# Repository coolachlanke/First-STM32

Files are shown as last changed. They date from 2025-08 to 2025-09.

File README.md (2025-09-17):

# My First STM32 Project

Simple PCB with minimum circuit plus SWD, USART, I2C and USB. Designed wholly in KiCAD 9.

---
Take a look a the fully sick 3D render:

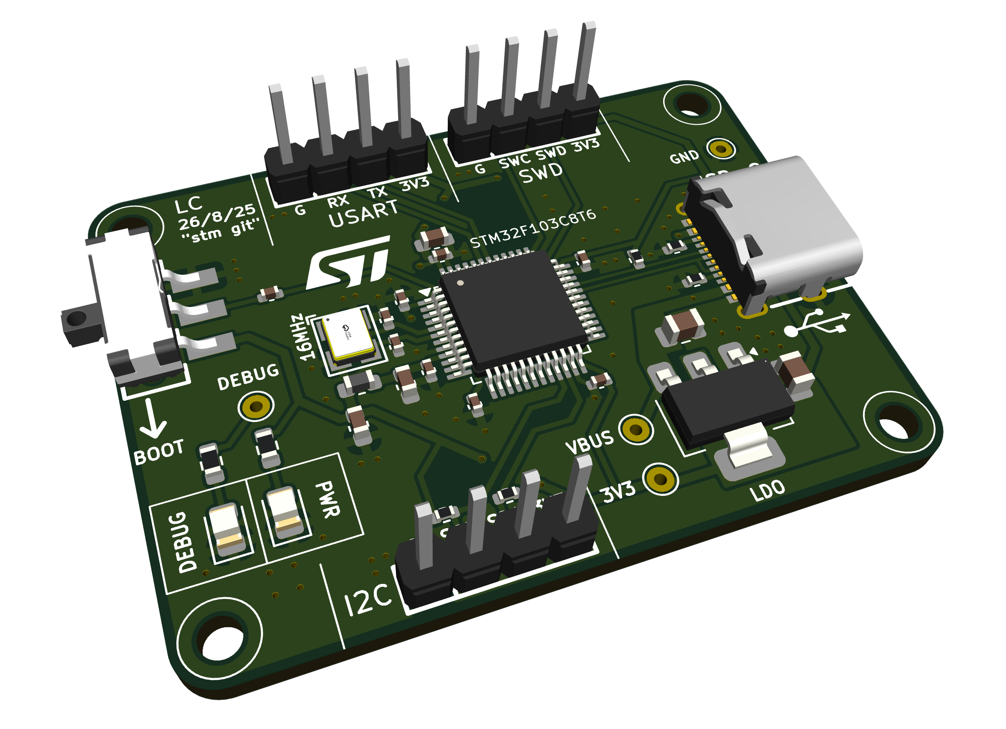
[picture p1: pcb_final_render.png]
pcb_render

---
..and now take a look at the fully sick assembled board:

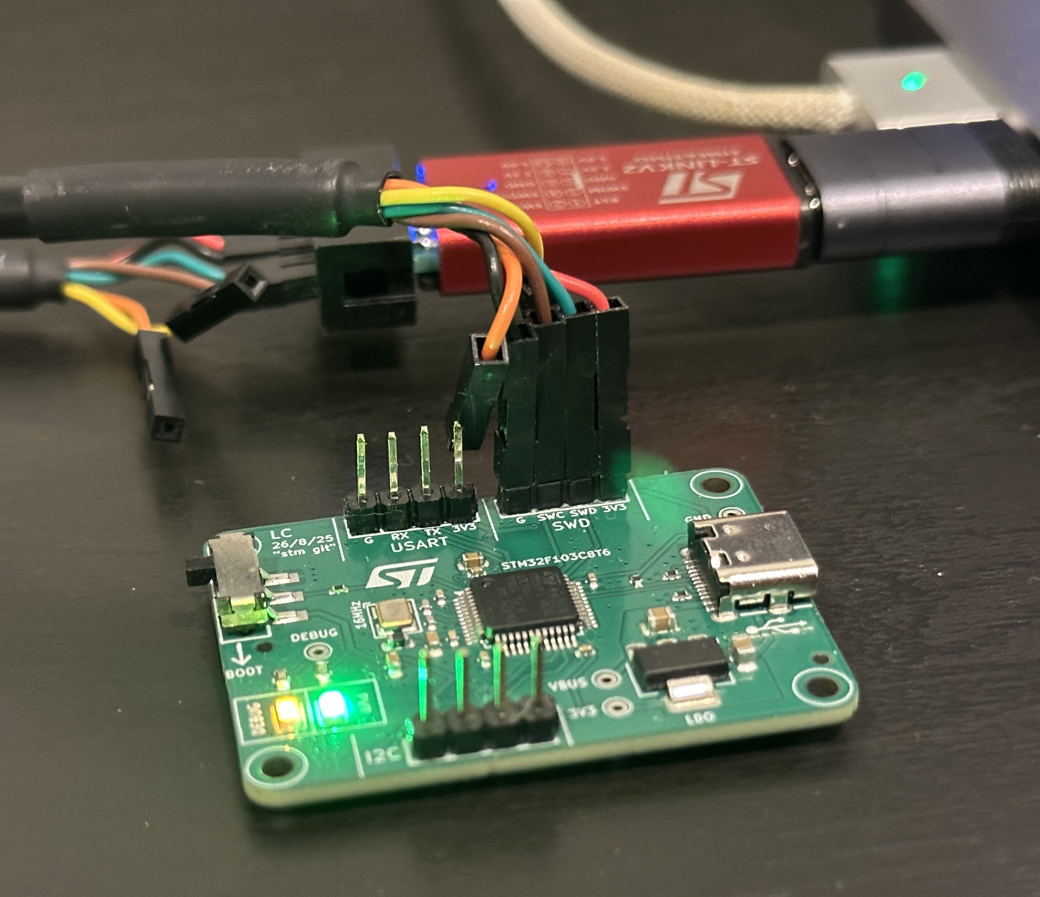
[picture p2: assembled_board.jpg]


The board's indicator LEDs are both on. The green 'PWR' LED indicates the 3V3 bus is live. The orange 'DEBUG' LED is a result of the 'blinky' routine being in the HIGH state.

---
The following HAL-free c script is used to blink the DEBUG LED by writing directly to memory-mapped peripheral registers.

```#include <stdint.h>

int main(void) {
    // Enable GPIOC clock
    volatile uint32_t *rcc_apb2enr = (volatile uint32_t *)0x40021018;
    *rcc_apb2enr |= (1 << 4); // Set IOPCEN (bit 4)

    // Configure PC13 as output push-pull, 10 MHz
    volatile uint32_t *gpioc_crh = (volatile uint32_t *)0x40011004;
    *gpioc_crh &= ~(0xF << 20); // Clear MODE13 and CNF13
    *gpioc_crh |= (0x1 << 20); // MODE13 = 01 (output 10 MHz), CNF13 = 00 (push-pull)

    // DR Register
    volatile uint32_t *gpioc_odr = (volatile uint32_t *)0x4001100C;

    // SysTick Registers
    volatile uint32_t *systick_ctrl = (volatile uint32_t *)0xE000E010;
    volatile uint32_t *systick_load = (volatile uint32_t *)0xE000E014;
    volatile uint32_t *systick_val  = (volatile uint32_t *)0xE000E018;

    // SysTick Init
    *systick_load = (8000000 / 1000) - 1;  // Reload for 1ms tick
    *systick_val  = 0;                     // Clear current value
    *systick_ctrl = (1 << 2) | (1 << 0);   // CLKSOURCE=CPU, ENABLE=1

    // Delay Function
    void delay_ms(uint32_t ms) {
        for (uint32_t i = 0; i < ms; ++i) {
            while (((*systick_ctrl) & (1 << 16)) == 0);
        }
    }

    // Main Blink Loop
    while (1) {
        *gpioc_odr &= ~(1 << 13);  // Set PC13 LOW
        delay_ms(250);

        *gpioc_odr |= (1 << 13);   // Set PC13 HIGH
        delay_ms(250);
    }
}

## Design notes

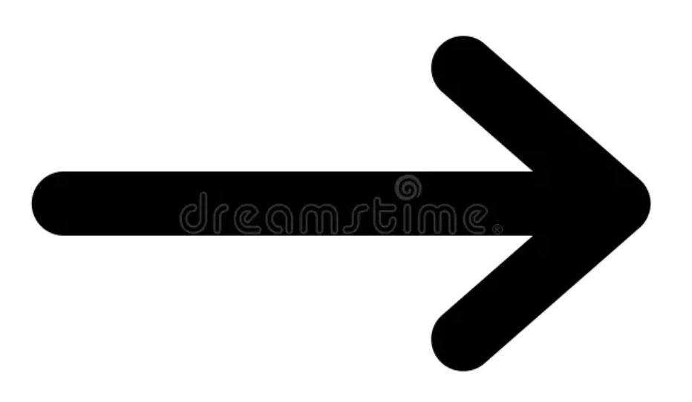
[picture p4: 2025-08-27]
arron.png

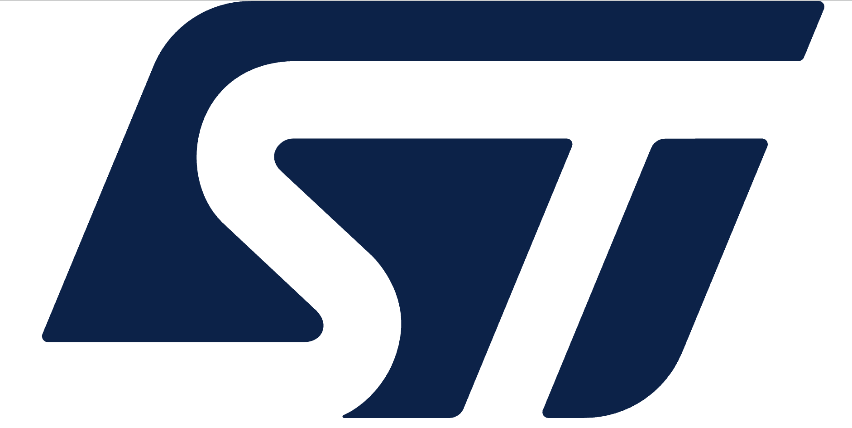
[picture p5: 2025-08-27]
st.png

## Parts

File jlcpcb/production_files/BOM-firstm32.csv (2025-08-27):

Comment | Designator | Footprint | LCSC | Quantity
16MHz | Y1 | OSC-SMD_4P-L3.2-W2.5-BL | C13738 | 1
120R @ 100MHz | FB1 | L_0603_1608Metric | C14709 | 1
10n | C6 | C_0402_1005Metric | C15195 | 1
100n | C1,C2,C3,C4,C9 | C_0402_1005Metric | C1525 | 5
1u | C7,C8 | C_0603_1608Metric | C15849 | 2
10u | C5 | C_0603_1608Metric | C19702 | 1
1k | R6 | R_0603_1608Metric | C21190 | 1
YELLOW | D2 | LED_0805_2012Metric | C2296 | 1
GREEN | D1 | LED_0805_2012Metric | C2297 | 1
470R | R5 | R_0603_1608Metric | C23179 | 1
10k | R1 | C_0402_1005Metric | C25744 | 1
1k5 | R4,R7,R8 | R_0402_1005Metric | C25867 | 3
5k1 | R2,R3 | R_0402_1005Metric | C25905 | 2
Conn_01x04_Pin | J2,J3,J4 | HDR-TH_4P-P2.54-V-M | C2691448 | 3
USB_C_Receptacle_USB2.0_16P | J1 | USB-C-SMD_TYPE-C-6PIN-2MD-073 | C2765186 | 1
10p | C10,C11 | C_0402_1005Metric | C32949 | 2
22u | C12,C13 | C_0805_2012Metric | C45783 | 2
AMS1117-3.3 | U1 | SOT-223-3_TabPin2 | C6186 | 1
STM32F103C8T6 | U2 | LQFP-48_7x7mm_P0.5mm | C8734 | 1
SW_SPDT | SW1 | SW-SMD_K3-1280S-K1 | C92658 | 1
TestPoint | TP4 | TestPoint_THTPad_D1.5mm_Drill0.7mm |  | 1
TestPoint | TP2 | TestPoint_THTPad_D1.5mm_Drill0.7mm |  | 1
TestPoint | TP1 | TestPoint_THTPad_D1.5mm_Drill0.7mm |  | 1
TestPoint | TP3 | TestPoint_THTPad_D1.5mm_Drill0.7mm |  | 1

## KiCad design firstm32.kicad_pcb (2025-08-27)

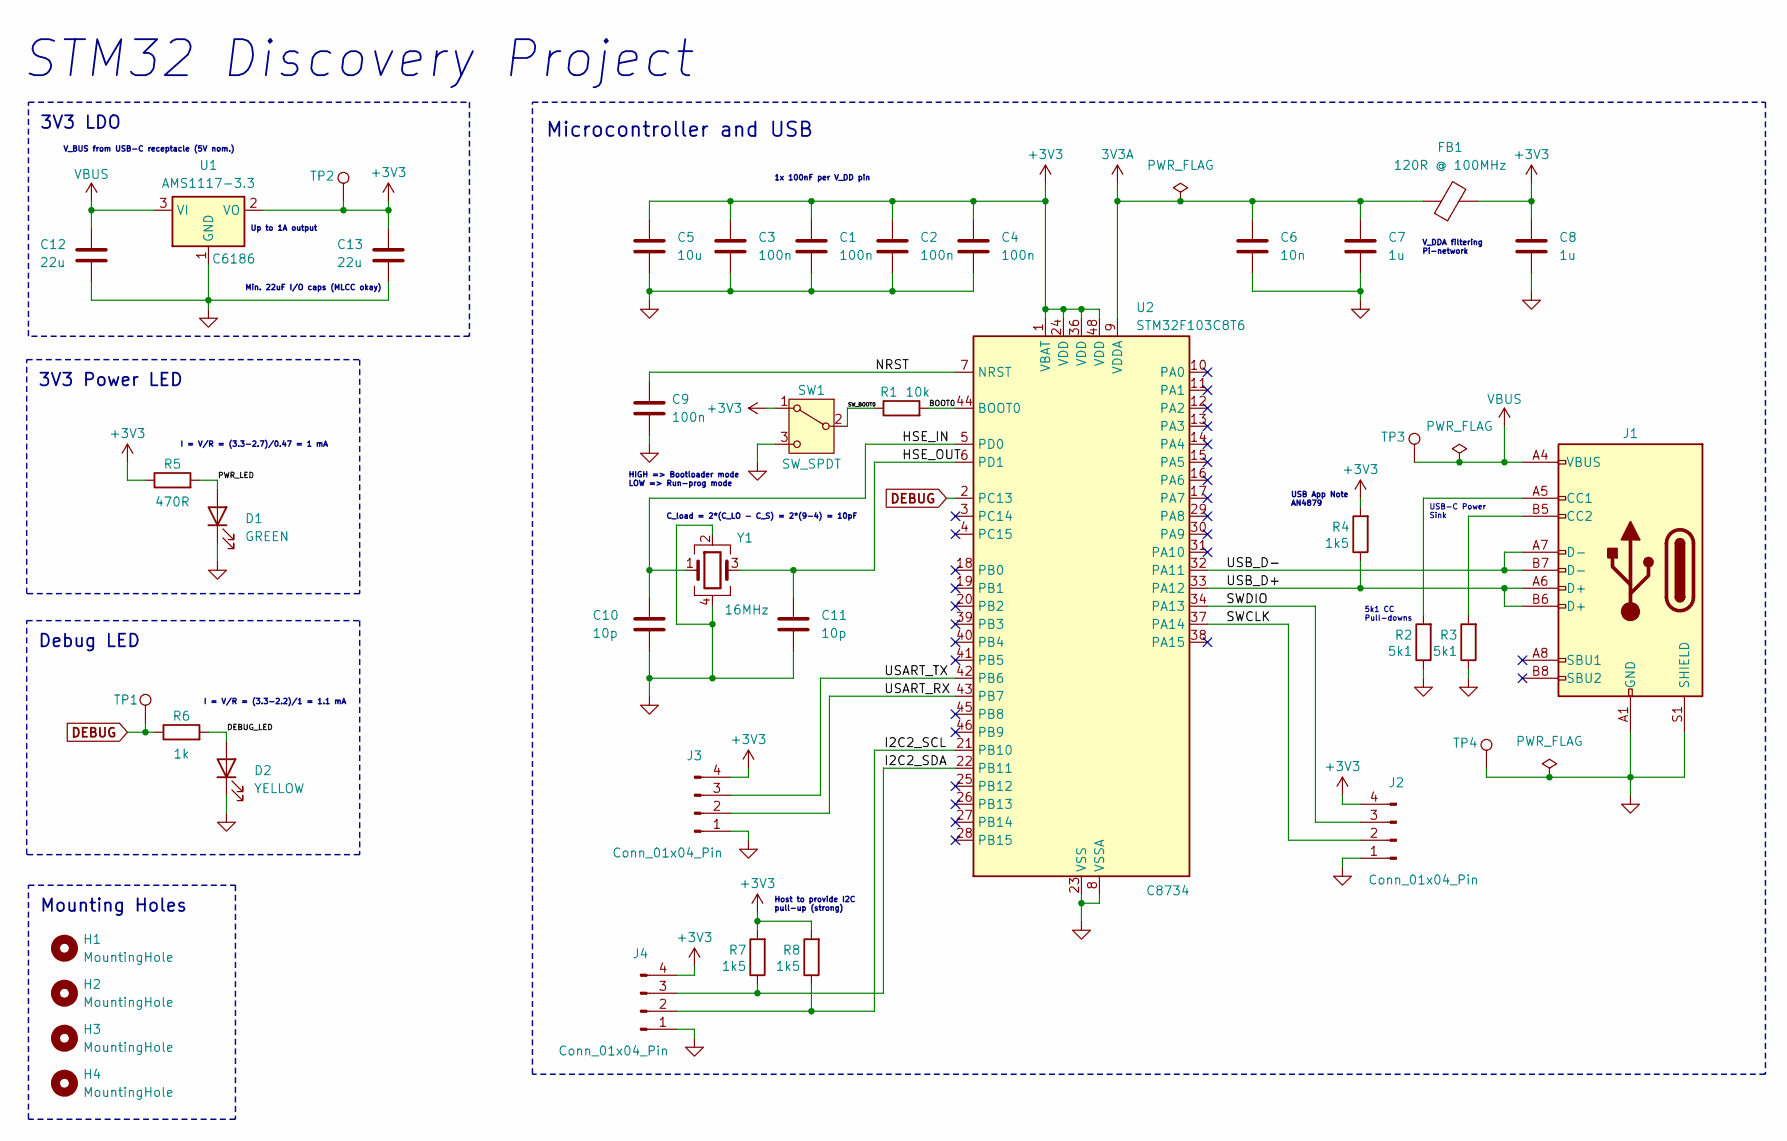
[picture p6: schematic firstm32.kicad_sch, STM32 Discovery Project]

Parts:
C1, C2, C3, C4, C9: 100n; C_0402_1005Metric; LCSC C1525
C5: 10u; C_0603_1608Metric; LCSC C19702
C6: 10n; C_0402_1005Metric; LCSC C15195
C7, C8: 1u; C_0603_1608Metric; LCSC C15849
C10, C11: 10p; C_0402_1005Metric; LCSC C32949
C12, C13: 22u; C_0805_2012Metric; LCSC C45783
D1: GREEN; LED_0805_2012Metric; LCSC C2297
D2: YELLOW; LED_0805_2012Metric; LCSC C2296
FB1: 120R @ 100MHz; L_0603_1608Metric; LCSC C14709
H1, H2, H3, H4: MountingHole; MountingHole_2.2mm_M2
J1: USB_C_Receptacle_USB2.0_16P; USB-C-SMD_TYPE-C-6PIN-2MD-073; LCSC C2765186
J2, J3, J4: Conn_01x04_Pin; HDR-TH_4P-P2.54-V-M; LCSC C2691448
R1: 10k; C_0402_1005Metric; LCSC C25744
R2, R3: 5k1; R_0402_1005Metric; LCSC C25905
R4, R7, R8: 1k5; R_0402_1005Metric; LCSC C25867
R5: 470R; R_0603_1608Metric; LCSC C23179
R6: 1k; R_0603_1608Metric; LCSC C21190
SW1: SW_SPDT; SW-SMD_K3-1280S-K1; LCSC C92658
TP1, TP2, TP3, TP4: TestPoint; TestPoint_THTPad_D1.5mm_Drill0.7mm
U1: AMS1117-3.3; SOT-223-3_TabPin2; LCSC C6186
U2: STM32F103C8T6; LQFP-48_7x7mm_P0.5mm; LCSC C8734
Y1: 16MHz; OSC-SMD_4P-L3.2-W2.5-BL; LCSC C13738

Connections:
3V3A: C6.1, C7.1, FB1.1, U2.9 (VDDA)
+3V3: C1.1, C2.1, C3.1, C4.1, C5.1, C8.1, C13.1, FB1.2, J2.4, J3.4, J4.4, R4.2, R5.1, R7.2, R8.2, SW1.1 (A), TP2.1, U1.2 (VO), U2.1 (VBAT), U2.24 (VDD), U2.36 (VDD), U2.48 (VDD)
/BOOT0: R1.2, U2.44 (BOOT0)
/DEBUG_LED: D2.2 (A), R6.2
/HSE_IN: C10.1, U2.5 (PD0), Y1.1
/HSE_OUT: C11.1, U2.6 (PD1), Y1.3
/I2C2_SCL: J4.2, R8.1, U2.21 (PB10)
/I2C2_SDA: J4.3, R7.1, U2.22 (PB11)
/NRST: C9.1, U2.7 (NRST)
/PWR_LED: D1.2 (A), R5.2
/SWCLK: J2.2, U2.37 (PA14)
/SWDIO: J2.3, U2.34 (PA13)
/SW_BOOT0: R1.1, SW1.2 (B)
/USART_RX: J3.2, U2.43 (PB7)
/USART_TX: J3.3, U2.42 (PB6)
/USB_D+: J1.A6 (D+), J1.B6 (D+), R4.1, U2.33 (PA12)
/USB_D-: J1.A7 (D-), J1.B7 (D-), U2.32 (PA11)
DEBUG: R6.1, TP1.1, U2.2 (PC13)
GND: C1.2, C2.2, C3.2, C4.2, C5.2, C6.2, C7.2, C8.2, C9.2, C10.2, C11.2, C12.2, C13.2, D1.1 (K), D2.1 (K), J1.A1 (GND), J1.A12 (GND), J1.B1 (GND), J1.B12 (GND), J1.S1 (SHIELD), J2.1, J3.1, J4.1, R2.1, R3.1, SW1.3 (C), TP4.1, U1.1 (GND), U2.8 (VSSA), U2.23 (VSS), U2.35 (VSS), U2.47 (VSS), Y1.2, Y1.4
unnamed: J1.A5 (CC1), R2.2
unnamed: J1.B5 (CC2), R3.2
VBUS: C12.1, J1.A4 (VBUS), J1.A9 (VBUS), J1.B4 (VBUS), J1.B9 (VBUS), TP3.1, U1.3 (VI)

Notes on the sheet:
I = V/R = (3.3-2.7)/0.47 = 1 mA
Up to 1A output
Debug LED
HIGH => Bootloader mode LOW => Run-prog mode
5k1 CC Pull-downs
Min. 22uF I/O caps (MLCC okay)
C_load = 2*(C_LO - C_S) = 2*(9-4) = 10pF
V_DDA filtering Pi-network
V_BUS from USB-C receptacle (5V nom.)
USB-C Power Sink
USB App Note AN4879
1x 100nF per V_DD pin
Host to provide I2C pull-up (strong)
3V3 Power LED
Mounting Holes
I = V/R = (3.3-2.2)/1 = 1.1 mA
STM32 Discovery Project
Microcontroller and USB
3V3 LDO

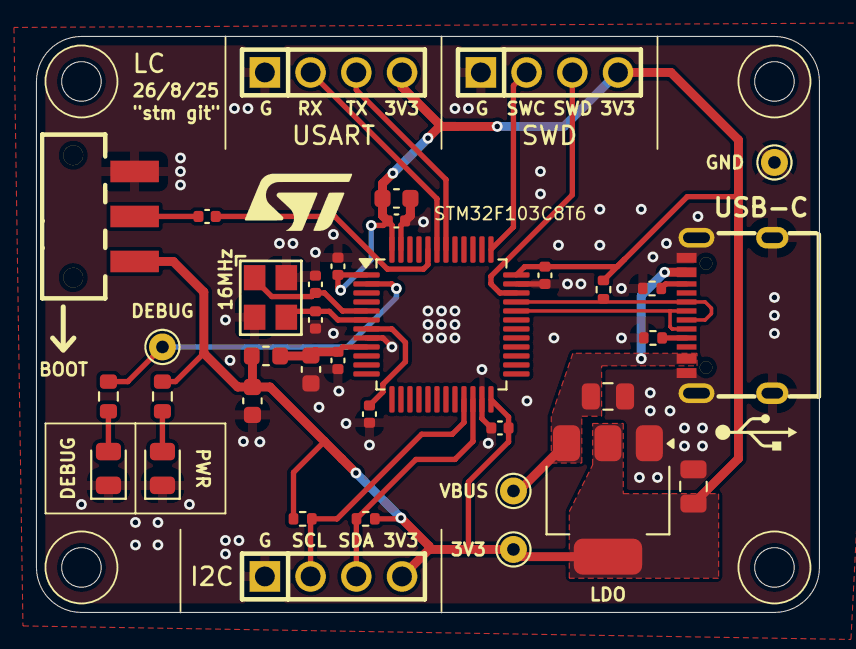
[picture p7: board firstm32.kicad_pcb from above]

Board: 2 copper layers, 43.5 x 32.0 mm, 40 parts (0 on the bottom side), 22 nets.

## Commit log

2025-08-26 Initial commit.
    [firstm32.kicad_pcb, firstm32.kicad_sch]
2025-08-26 Finished board layout
    [firstm32.kicad_pcb, firstm32.kicad_sch]
2025-08-27 Finalised board and ordered with JLCPCC + PCBA
    [BOM-firstm32.csv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]
2025-09-02 Added assembled board image
